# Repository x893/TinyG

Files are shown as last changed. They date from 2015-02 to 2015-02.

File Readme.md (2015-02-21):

TinyG board with BT
TinyG board with USB

Software from https://github.com/synthetos/TinyG

xboot-BT : change for Bluetooth module

xboot-loader : utility to upload (MS Visual Studio 2013) upload program with parameters -b 115200 -P COM14 -U flash:w:tinyg.hex

hardware : design files for http://akb77.com/g/cnc/tinyg-controller-for-cnc/

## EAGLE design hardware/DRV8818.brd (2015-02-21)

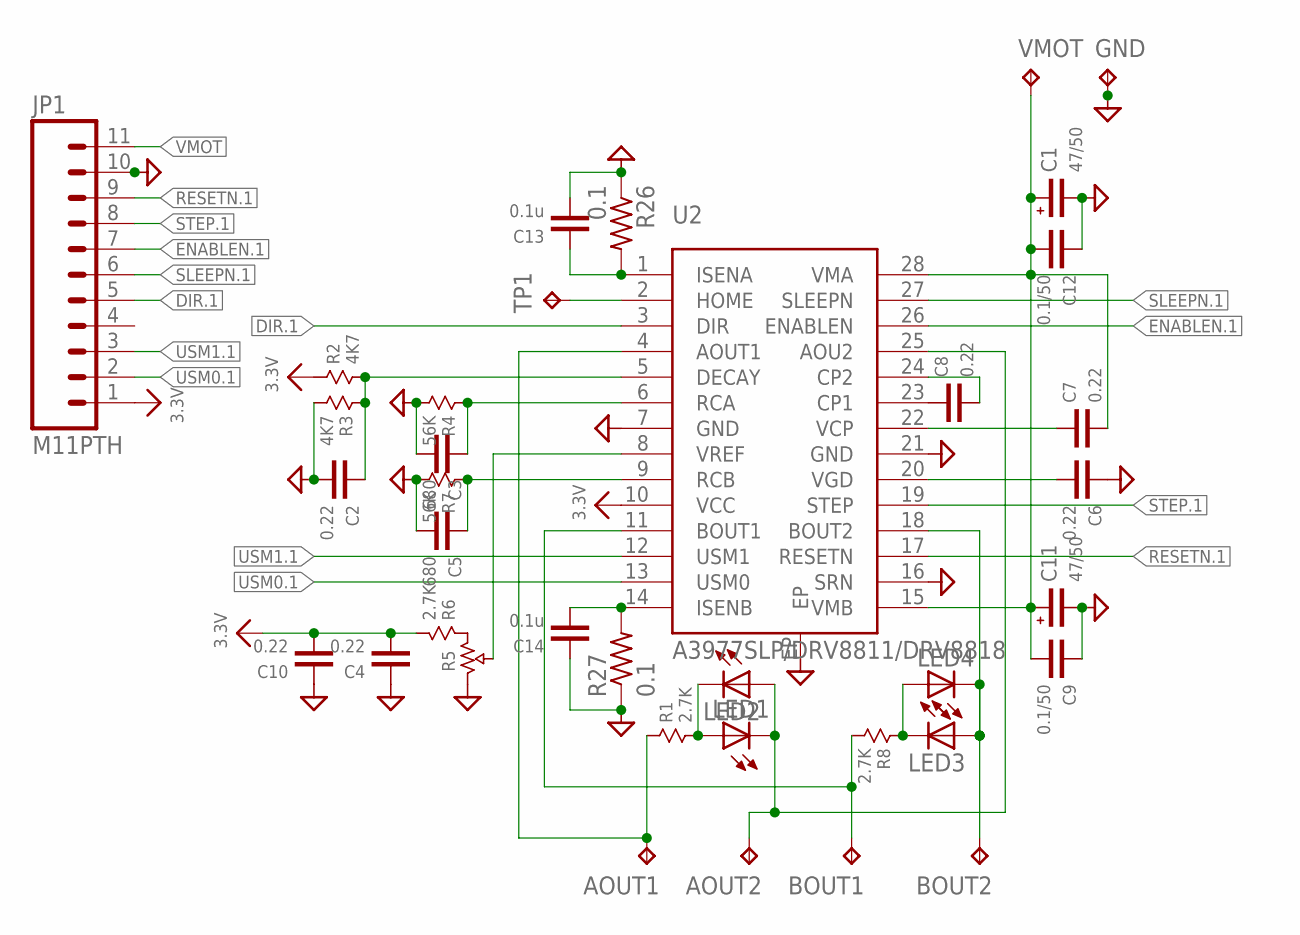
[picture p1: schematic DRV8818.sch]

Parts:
AOUT1, AOUT2: TPTP20R; TP20R
BOUT1, BOUT2: TPTP20R; TP20R
C1, C11: 47/50; CT7343
C2, C4, C6, C7, C8, C10: 0.22; 0603
C3, C5: 680; 0603
C9, C12: 0.1/50; 0603
C13, C14: 0.1u; 0603
GND: TPTP20R; TP20R
JP1: M11PTH; 1X11
LED1, LED2, LED3, LED4: LEDCHIP-LED0603; CHIP-LED0603
R1, R6, R8: 2.7K; 0603
R2, R3: 4K7; 0603
R4, R7: 56K; 0603
R5: PVZ3A
R26, R27: 0.1; R2512
TP1: TPTP08R; TP08R
U2: A3977SLP/DRV8811/DRV8818; SSOP28EP
VMOT: TPTP20R; TP20R

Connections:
3.3V: C4.1, C10.1, JP1.1, R2.1, R6.2, U2.10 (VCC)
AOUT1: AOUT1.TP, R1.1, U2.4 (AOUT1)
AOUT2: AOUT2.TP, LED1.C, LED2.A, U2.25 (AOU2)
BOUT1: BOUT1.TP, R8.2, U2.11 (BOUT1)
BOUT2: BOUT2.TP, LED3.A, LED4.C, U2.18 (BOUT2)
DIR.1: JP1.5, U2.3 (DIR)
ENABLEN.1: JP1.7, U2.26 (ENABLEN)
GND: C1.-, C2.1, C3.1, C4.2, C5.1, C6.2, C9.2, C10.2, C11.-, C12.2, C13.1, C14.2, GND.TP, JP1.10, R3.2, R4.2, R5.1, R7.2, R26.1, R27.1, U2.7 (GND), U2.16 (SRN), U2.21 (GND), U2.EP
unnamed: C14.1, R27.2, U2.14 (ISENB)
unnamed: LED3.C, LED4.A, R8.1
unnamed: LED1.A, LED2.C, R1.2
unnamed: C2.2, R2.2, R3.1, U2.5 (DECAY)
unnamed: C3.2, R4.1, U2.6 (RCA)
unnamed: R5.3, R6.1
unnamed: R5.2, U2.8 (VREF)
unnamed: C5.2, R7.1, U2.9 (RCB)
unnamed: C13.2, R26.2, U2.1 (ISENA)
unnamed: TP1.TP, U2.2 (HOME)
unnamed: C7.2, U2.22 (VCP)
unnamed: C6.1, U2.20 (VGD)
unnamed: C8.2, U2.23 (CP1)
unnamed: C8.1, U2.24 (CP2)
RESETN.1: JP1.9, U2.17 (RESETN)
SLEEPN.1: JP1.6, U2.27 (SLEEPN)
STEP.1: JP1.8, U2.19 (STEP)
USM0.1: JP1.2, U2.13 (USM0)
USM1.1: JP1.3, U2.12 (USM1)
VMOT: C1.+, C7.1, C9.1, C11.+, C12.1, JP1.11, U2.15 (VMB), U2.28 (VMA), VMOT.TP

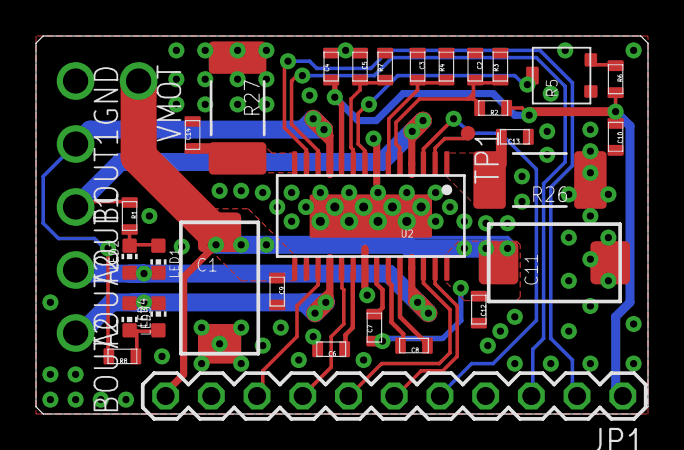
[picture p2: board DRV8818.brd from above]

Board: 2 copper layers, 34.0 x 21.0 mm, 37 parts (0 on the bottom side), 28 nets.

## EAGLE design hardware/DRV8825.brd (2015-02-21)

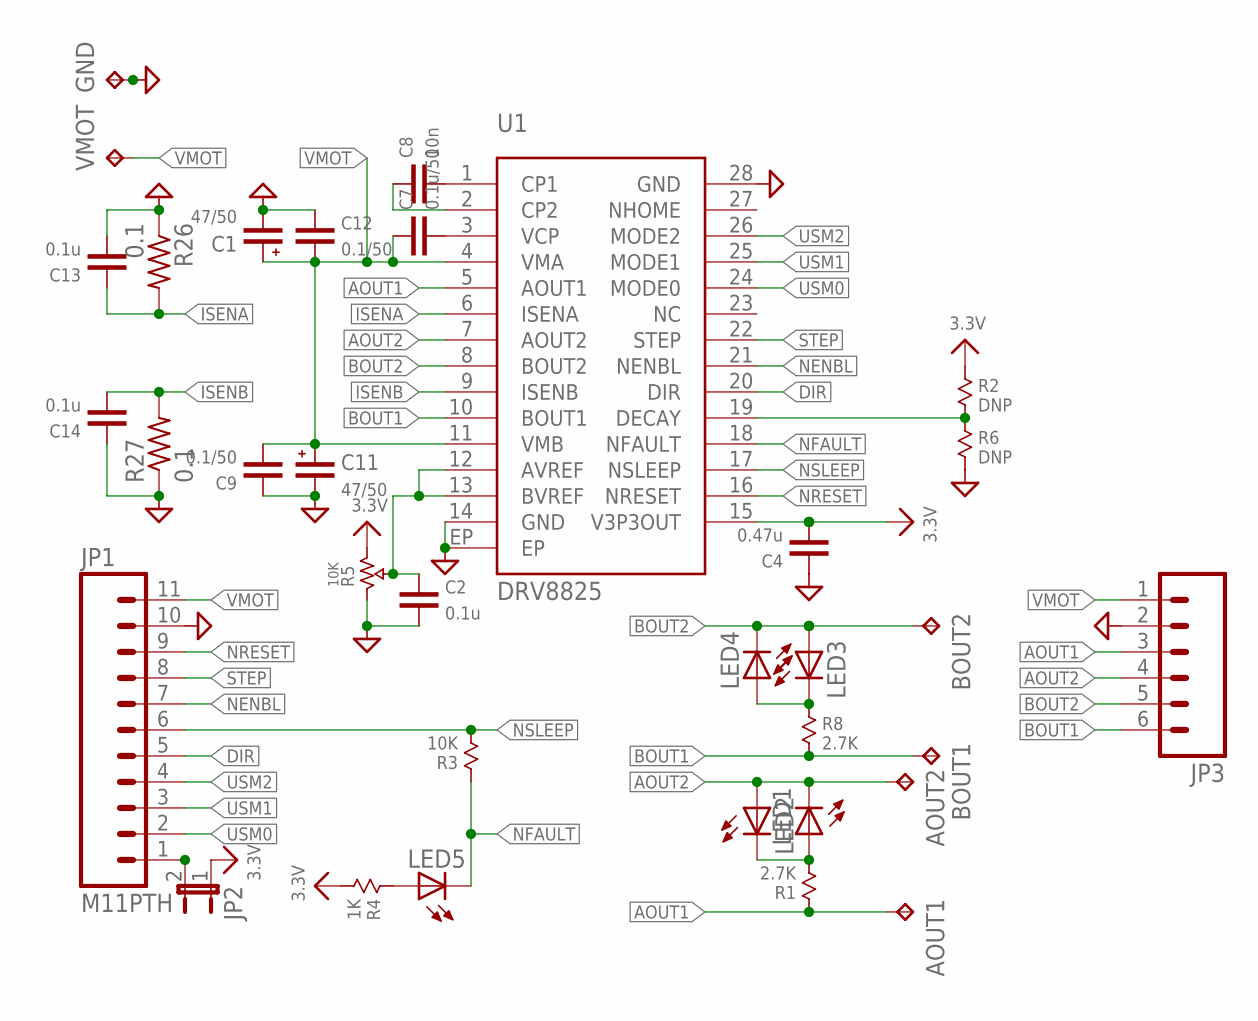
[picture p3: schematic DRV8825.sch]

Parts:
AOUT1, AOUT2: TPTP18R; TP18R
BOUT1, BOUT2: TPTP18R; TP18R
C1, C11: 47/50; CT7343
C2, C13, C14: 0.1u; 0603
C4: 0.47u; 0603
C7: 0.1u/50; 0603
C8: 10n; 0603
C9, C12: 0.1/50; 0603
GND: TPTP18R; TP18R
JP1: M11PTH; 1X11
JP2: JUMPER-2SMD-NO; SJ_2S-NO
JP3: M06SIP; 1X06
LED1, LED2, LED3, LED4, LED5: LEDCHIP-LED0603; CHIP-LED0603
R1, R8: 2.7K; 0603
R2, R6: DNP; 0603
R3: 10K; 0603
R4: 1K; 0603
R5: 10K; PVZ3A
R26, R27: 0.1; R2512
U1: DRV8825; SSOP28EP
VMOT: TPTP18R; TP18R

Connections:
3.3V: C4.1, JP2.1, R2.1, R4.2, R5.3, U1.15 (V3P3OUT)
AOUT1: AOUT1.TP, JP3.3, R1.1, U1.5 (AOUT1)
AOUT2: AOUT2.TP, JP3.4, LED1.C, LED2.A, U1.7 (AOUT2)
BOUT1: BOUT1.TP, JP3.6, R8.2, U1.10 (BOUT1)
BOUT2: BOUT2.TP, JP3.5, LED3.A, LED4.C, U1.8 (BOUT2)
DIR: JP1.5, U1.20 (DIR)
GND: C1.-, C2.1, C4.2, C9.2, C11.-, C12.2, C13.1, C14.2, GND.TP, JP1.10, JP3.2, R5.1, R6.2, R26.1, R27.1, U1.14 (GND), U1.28 (GND), U1.EP
ISENA: C13.2, R26.2, U1.6 (ISENA)
ISENB: C14.1, R27.2, U1.9 (ISENB)
unnamed: C8.1, U1.1 (CP1)
unnamed: LED3.C, LED4.A, R8.1
unnamed: LED1.A, LED2.C, R1.2
unnamed: C8.2, U1.2 (CP2)
unnamed: LED5.A, R4.1
unnamed: C7.1, U1.3 (VCP)
unnamed: C2.2, R5.2, U1.12 (AVREF), U1.13 (BVREF)
unnamed: R2.2, R6.1, U1.19 (DECAY)
unnamed: JP1.1, JP2.2
NENBL: JP1.7, U1.21 (NENBL)
NFAULT: LED5.C, R3.1, U1.18 (NFAULT)
NRESET: JP1.9, U1.16 (NRESET)
NSLEEP: JP1.6, R3.2, U1.17 (NSLEEP)
STEP: JP1.8, U1.22 (STEP)
USM0: JP1.2, U1.24 (MODE0)
USM1: JP1.3, U1.25 (MODE1)
USM2: JP1.4, U1.26 (MODE2)
VMOT: C1.+, C7.2, C9.1, C11.+, C12.1, JP1.11, JP3.1, U1.4 (VMA), U1.11 (VMB), VMOT.TP

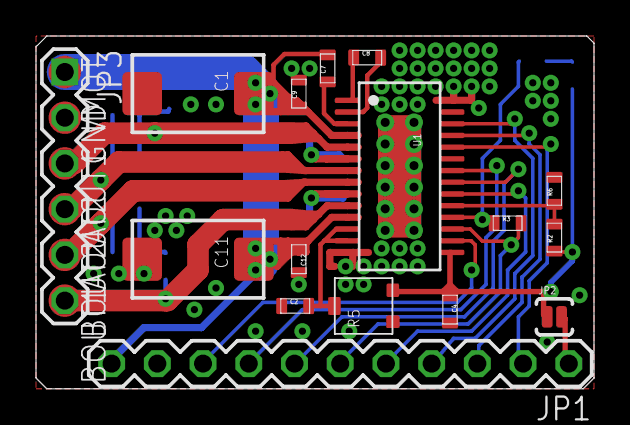
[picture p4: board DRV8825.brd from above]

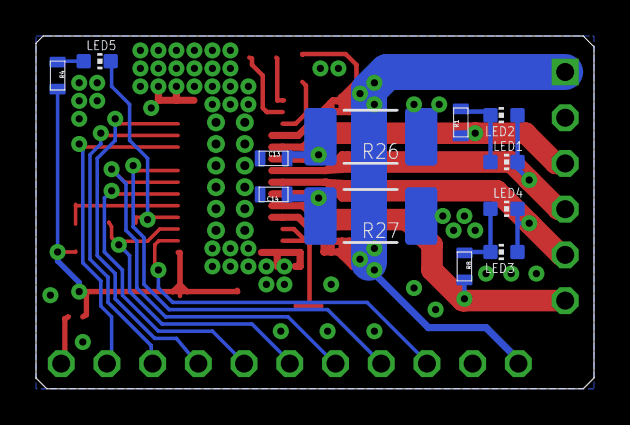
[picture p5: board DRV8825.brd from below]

Board: 2 copper layers, 31.0 x 19.6 mm, 34 parts (12 on the bottom side), 27 nets.

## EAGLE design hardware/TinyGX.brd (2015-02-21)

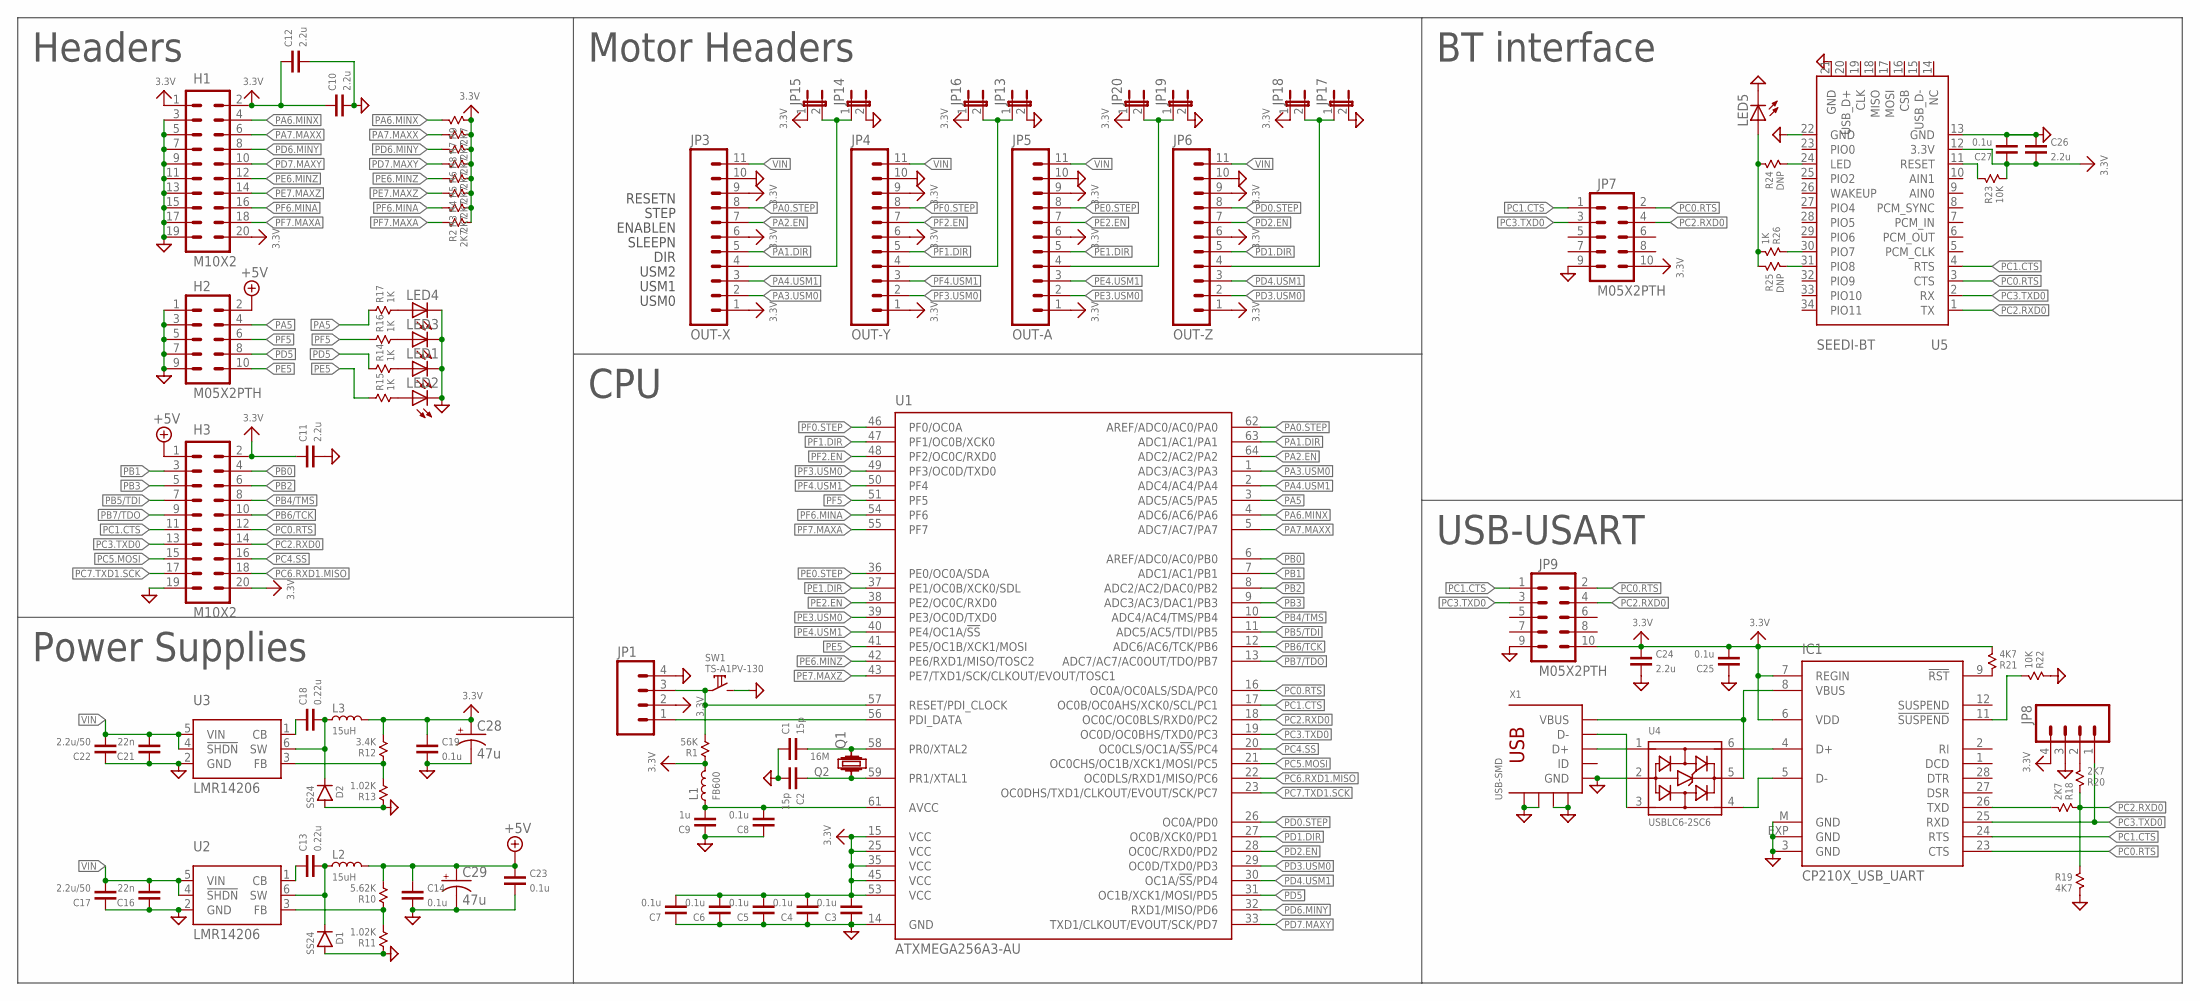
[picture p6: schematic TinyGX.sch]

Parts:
C1, C2: 15p; 0603
C3, C4, C5, C6, C7, C8, C14, C19, C23, C25, C27: 0.1u; 0603
C9: 1u; 0603
C10, C11, C12, C24, C26: 2.2u; 0603
C13, C18: 0.22u; 0603
C16, C21: 22n; 0603
C17, C22: 2.2u/50; 1206
C28, C29: 47u; CT3216
D1, D2: SS24; SMA
H1, H3: M10X2; 2X10
H2: M05X2PTH; AVR_ICSP
IC1: CP210X_USB_UART; MLP28
JP1, JP8: M04PTH; 1X04
JP3: OUT-X; 1X11
JP4: OUT-Y; 1X11
JP5: OUT-A; 1X11
JP6: OUT-Z; 1X11
JP7, JP9: M05X2PTH; AVR_ICSP
JP13, JP14, JP15, JP16, JP17, JP18, JP19, JP20: JUMPER-2SMD-NO; SJ_2S-NO
L1: FB600; 0603
L2, L3: 15uH; CDRH73
LED1, LED2, LED3, LED4, LED5: LEDCHIP-LED0603; CHIP-LED0603
Q1: CRYSTALHC49US; HC49US
Q2: 16M; KX-KT
R1: 56K; 0603
R2, R3, R4, R5, R6, R7, R8, R9, R18, R20: 2K7; 0603
R10: 5.62K; 0603
R11, R13: 1.02K; 0603
R12: 3.4K; 0603
R14, R15, R16, R17, R26: 1K; 0603
R19, R21: 4K7; 0603
R22, R23: 10K; 0603
R24, R25: DNP; 0603
SW1: TS-A1PV-130
U1: ATXMEGA256A3-AU; TQFP64-14X14
U2, U3: LMR14206; SOT23-6
U4: USBLC6-2SC6; SOT23-6
U5: SEEDI-BT
X1: USB-SMD; USB-MINIB

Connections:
3.3V: C3.1, C4.1, C5.1, C6.1, C7.1, C10.2, C11.2, C12.2, C19.2, C24.2, C25.1, C26.1, C27.2, C28.+, H1.1, H1.2, H1.20, H3.2, H3.20, IC1.6 (VDD), IC1.7 (REGIN), JP1.2, JP3.1, JP3.6, JP3.9, JP4.1, JP4.6, JP4.9, JP5.1, JP5.6, JP5.9, JP6.1, JP6.6, JP6.9, JP7.10, JP8.4, JP9.10, JP15.1, JP16.1, JP18.1, JP20.1, L1.2, L3.P$2 (2), R1.1, R2.2, R3.2, R4.2, R5.2, R6.2, R7.2, R8.2, R9.2, R12.2, R21.2, R23.2, U1.15 (VCC), U1.25 (VCC), U1.35 (VCC), U1.45 (VCC), U1.53 (VCC), U5.12 (3.3V)
+5V: C14.2, C23.2, C29.+, H2.2, H3.1, L2.P$2 (2), R10.2
GND: C1.2, C2.1, C3.2, C4.2, C5.2, C6.2, C7.2, C8.2, C9.2, C10.1, C11.1, C12.1, C14.1, C16.2, C17.2, C19.1, C21.2, C22.2, C23.1, C24.1, C25.2, C26.2, C27.1, C28.-, C29.-, D1.P$2 (A), D2.P$2 (A), H1.3, H1.5, H1.7, H1.9, H1.11, H1.13, H1.15, H1.17, H1.19, H2.1, H2.3, H2.5, H2.7, H2.9, H3.19, IC1.3 (GND), IC1.EXP (GND), IC1.M (GND), JP1.4, JP3.10, JP4.10, JP5.10, JP6.10, JP7.9, JP8.3, JP9.9, JP13.2, JP14.2, JP17.2, JP19.2, LED1.C, LED2.C, LED3.C, LED4.C, LED5.C, R11.1, R13.1, R19.2, R22.1, SW1.2, U1.14 (GND), U1.24 (GND), U1.34 (GND), U1.44 (GND), U1.52 (GND), U1.60 (GND), U2.2 (GND), U3.2 (GND), U4.2 (GND), U5.13 (GND), U5.21 (GND), U5.22 (GND), X1.GND, X1.GND@1 (GND), X1.GND@2 (GND), X1.GND@3 (GND), X1.GND@4 (GND)
unnamed: C1.1, Q1.2, Q2.2, U1.58 (PR0/XTAL2)
unnamed: C2.2, Q1.1, Q2.1, U1.59 (PR1/XTAL1)
unnamed: R10.1, R11.2, U2.3 (FB)
unnamed: LED1.A, R14.2
unnamed: C13.1, D1.P$1 (C), L2.P$1 (1), U2.6 (SW)
unnamed: R12.1, R13.2, U3.3 (FB)
unnamed: C13.2, U2.1 (CB)
unnamed: C8.1, C9.1, L1.1, U1.61 (AVCC)
unnamed: C18.1, D2.P$1 (C), L3.P$1 (1), U3.6 (SW)
unnamed: C18.2, U3.1 (CB)
unnamed: LED2.A, R15.2
unnamed: LED3.A, R16.2
unnamed: LED4.A, R17.2
unnamed: IC1.5 (D-), U4.4 (IO2)
unnamed: IC1.4 (D+), U4.6 (IO1)
unnamed: IC1.8 (VBUS), U4.5 (VBUS), X1.VBUS
unnamed: JP8.2, R20.2
unnamed: IC1.26 (TXD), R18.2
unnamed: IC1.9 (!RST), R21.1
unnamed: U4.3 (IO2), X1.D-
unnamed: U4.1 (IO1), X1.D+
unnamed: IC1.11 (!SUSPEND), R22.2
unnamed: JP3.4, JP14.1, JP15.2
unnamed: JP4.4, JP13.1, JP16.2
unnamed: JP5.4, JP19.1, JP20.2
unnamed: JP6.4, JP17.1, JP18.2
unnamed: R26.1, U5.30 (PIO7)
unnamed: R23.1, U5.11 (RESET)
unnamed: R24.2, U5.24 (LED)
unnamed: R25.2, U5.31 (PIO8)
unnamed: LED5.A, R24.1, R25.1, R26.2
PA0.STEP: JP3.8, U1.62 (AREF/ADC0/AC0/PA0)
PA1.DIR: JP3.5, U1.63 (ADC1/AC1/PA1)
PA2.EN: JP3.7, U1.64 (ADC2/AC2/PA2)
PA3.USM0: JP3.2, U1.1 (ADC3/AC3/PA3)
PA4.USM1: JP3.3, U1.2 (ADC4/AC4/PA4)
PA5: H2.4, R17.1, U1.3 (ADC5/AC5/PA5)
PA6.MINX: H1.4, R9.1, U1.4 (ADC6/AC6/PA6)
PA7.MAXX: H1.6, R7.1, U1.5 (ADC7/AC7/PA7)
PB0: H3.4, U1.6 (AREF/ADC0/AC0/PB0)
PB1: H3.3, U1.7 (ADC1/AC1/PB1)
PB2: H3.6, U1.8 (ADC2/AC2/DAC0/PB2)
PB3: H3.5, U1.9 (ADC3/AC3/DAC1/PB3)
PB4/TMS: H3.8, U1.10 (ADC4/AC4/TMS/PB4)
PB5/TDI: H3.7, U1.11 (ADC5/AC5/TDI/PB5)
PB6/TCK: H3.10, U1.12 (ADC6/AC6/TCK/PB6)
PB7/TDO: H3.9, U1.13 (ADC7/AC7/AC0OUT/TDO/PB7)
PC0.RTS: H3.12, IC1.23 (CTS), JP7.2, JP9.2, U1.16 (OC0A/OC0ALS/SDA/PC0), U5.3 (CTS)
PC1.CTS: H3.11, IC1.24 (RTS), JP7.1, JP9.1, U1.17 (OC0B/OC0AHS/XCK0/SCL/PC1), U5.4 (RTS)
PC2.RXD0: H3.14, JP7.4, JP9.4, R18.1, R19.1, R20.1, U1.18 (OC0C/OC0BLS/RXD0/PC2), U5.1 (TX)
PC3.TXD0: H3.13, IC1.25 (RXD), JP7.3, JP8.1, JP9.3, U1.19 (OC0D/OC0BHS/TXD0/PC3), U5.2 (RX)
PC4.SS: H3.16, U1.20 (OC0CLS/OC1A/!SS!/PC4)
PC5.MOSI: H3.15, U1.21 (OC0CHS/OC1B/XCK1/MOSI/PC5)
PC6.RXD1.MISO: H3.18, U1.22 (OC0DLS/RXD1/MISO/PC6)
PC7.TXD1.SCK: H3.17, U1.23 (OC0DHS/TXD1/CLKOUT/EVOUT/SCK/PC7)
PD0.STEP: JP6.8, U1.26 (OC0A/PD0)
PD1.DIR: JP6.5, U1.27 (OC0B/XCK0/PD1)
PD2.EN: JP6.7, U1.28 (OC0C/RXD0/PD2)
PD3.USM0: JP6.2, U1.29 (OC0D/TXD0/PD3)
PD4.USM1: JP6.3, U1.30 (OC1A/!SS!/PD4)
PD5: H2.8, R14.1, U1.31 (OC1B/XCK1/MOSI/PD5)
PD6.MINY: H1.8, R8.1, U1.32 (RXD1/MISO/PD6)
PD7.MAXY: H1.10, R6.1, U1.33 (TXD1/CLKOUT/EVOUT/SCK/PD7)
PDI: JP1.1, U1.56 (PDI_DATA)
PE0.STEP: JP5.8, U1.36 (PE0/OC0A/SDA)
PE1.DIR: JP5.5, U1.37 (PE1/OC0B/XCK0/SDL)
PE2.EN: JP5.7, U1.38 (PE2/OC0C/RXD0)
PE3.USM0: JP5.2, U1.39 (PE3/OC0D/TXD0)
PE4.USM1: JP5.3, U1.40 (PE4/OC1A/!SS)
PE5: H2.10, R15.1, U1.41 (PE5/OC1B/XCK1/MOSI)
PE6.MINZ: H1.12, R5.1, U1.42 (PE6/RXD1/MISO/TOSC2)
PE7.MAXZ: H1.14, R4.1, U1.43 (PE7/TXD1/SCK/CLKOUT/EVOUT/TOSC1)
PF0.STEP: JP4.8, U1.46 (PF0/OC0A)
PF1.DIR: JP4.5, U1.47 (PF1/OC0B/XCK0)
PF2.EN: JP4.7, U1.48 (PF2/OC0C/RXD0)
PF3.USM0: JP4.2, U1.49 (PF3/OC0D/TXD0)
PF4.USM1: JP4.3, U1.50 (PF4)
PF5: H2.6, R16.1, U1.51 (PF5)
PF6.MINA: H1.16, R3.1, U1.54 (PF6)
PF7.MAXA: H1.18, R2.1, U1.55 (PF7)
RST/PDC: JP1.3, R1.2, SW1.1, U1.57 (RESET/PDI_CLOCK)
VIN: C16.1, C17.1, C21.1, C22.1, JP3.11, JP4.11, JP5.11, JP6.11, U2.4 (!SHDN), U2.5 (VIN), U3.4 (!SHDN), U3.5 (VIN)

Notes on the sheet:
USM0
USM1
DIR
SLEEPN
ENABLEN
STEP
RESETN
USM2
BT interface
USB-USART
Motor Headers
CPU
Power Supplies
Headers

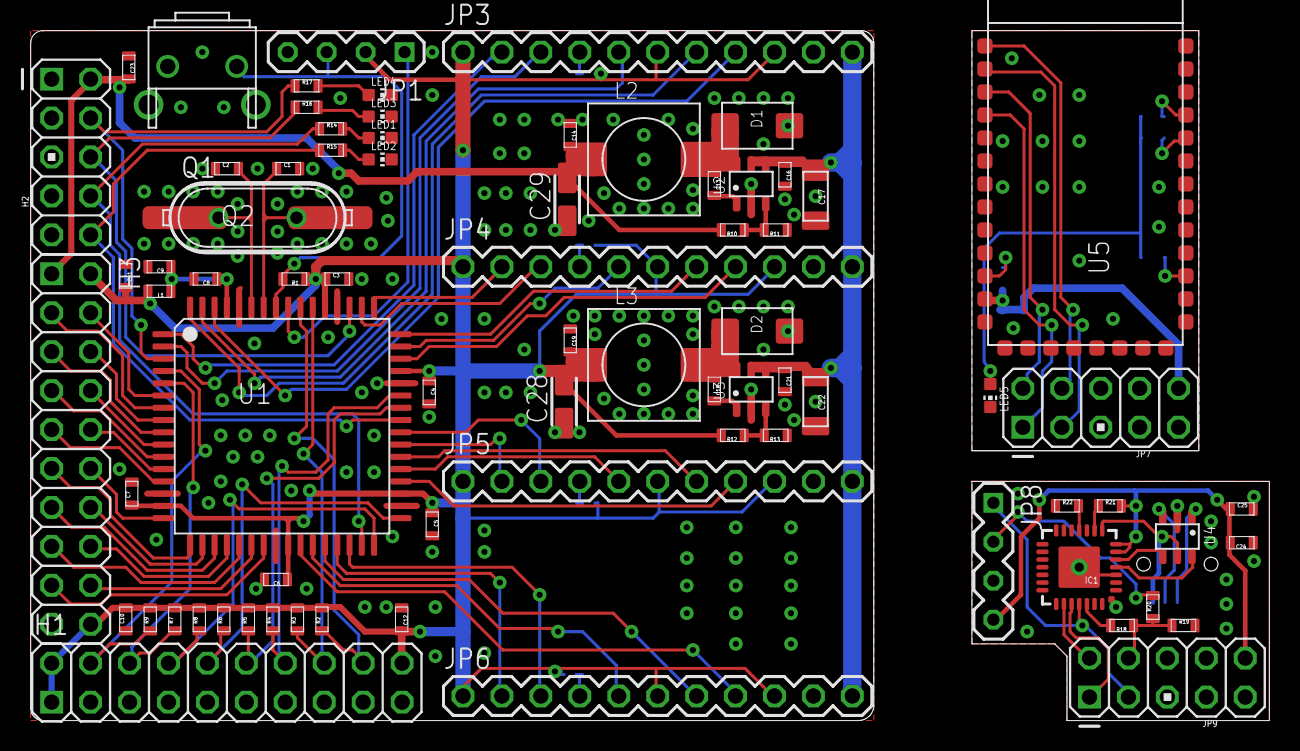
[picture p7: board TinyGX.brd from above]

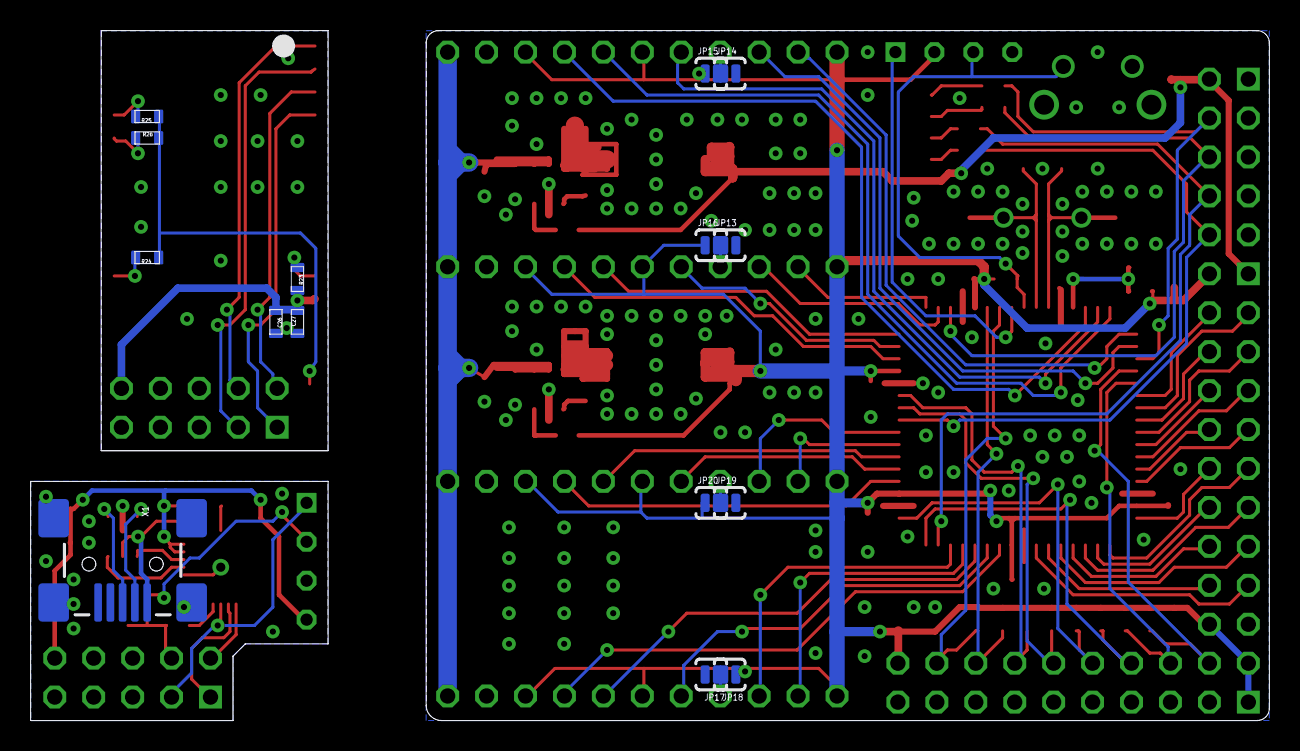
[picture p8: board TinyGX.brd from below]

Board: 2 copper layers, 80.8 x 45.0 mm, 92 parts (15 on the bottom side), 85 nets.

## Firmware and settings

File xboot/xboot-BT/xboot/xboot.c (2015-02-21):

#include "xboot.h"

unsigned char Buffer[SPM_PAGESIZE];
ADDR_T address;
uint16_t data;
uint8_t in_bootloader;
uint8_t val;
uint32_t led_delay;

typedef struct FirmwareInfo_s {
	uint32_t	Size;
	uint16_t	CRC16;
	} FirmwareInfo_t;

#define FWINFO_START	(APP_SECTION_START + APP_SECTION_SIZE - APP_SECTION_PAGE_SIZE)
uint8_t CheckAppImage(void);
void WriteAppChecksum(uint32_t size);

// Main code
int main(void)
{
	WDT_Disable();

	#ifdef USE_32MHZ_RC
		#if (F_CPU != 32000000L)
			#error F_CPU must match oscillator setting!
		#endif // F_CPU

		OSC.CTRL |= OSC_RC32MEN_bm;						// turn on 32 MHz oscillator
		while (!(OSC.STATUS & OSC_RC32MRDY_bm)) { };	// wait for it to start
		CCP = CCP_IOREG_gc;
		CLK.CTRL = CLK_SCLKSEL_RC32M_gc;

		#ifdef USE_DFLL
			DFLLRC32M.CTRL = DFLL_ENABLE_bm;
		#endif // USE_DFLL
	#else // USE_32MHZ_RC
		#if (F_CPU != 2000000L)
			#error F_CPU must match oscillator setting!
		#endif // F_CPU
		#ifdef USE_DFLL
			DFLLRC2M.CTRL = DFLL_ENABLE_bm;
		#endif // USE_DFLL
	#endif // USE_32MHZ_RC

	LED_INIT();
	// Bluetooth initialization 
	UART_INIT(USART_BAUD_9600);
	UART_Send_B("AT+BAUD8");		// Set speed 115200
	_delay_ms(1000);
	UART_INIT(USART_BAUD_115200);	// Change USART to 115200
	UART_Send_B("AT+NAMETinyG");	// Set BT device name
	_delay_ms(1000);
	UART_Send_B("AT+PIN1963");		// Set BT password
	_delay_ms(1000);

	// Correct CRC, enable auto jump to application
	in_bootloader = CheckAppImage();
	//	in_bootloader == 1	CRC not correct, never jump to application
	//	in_bootloader == 2	CRC correct, after small delay go to application
	data = 0;
	address = 0;
	led_delay = 0;
	while (in_bootloader)	// Main bootloader
	{
		val = get_char_nowait();
		if (val == 0)
		{
			led_delay++;
			if (led_delay == LED_ON_DELAY)
			{
				LED_ON();
			}
			else if (led_delay == LED_OFF_DELAY)
			{
				LED_OFF();
				led_delay = 0;
				if (in_bootloader == XB_BOOT_DELAY)
				{	// Jump to application
					in_bootloader = 0;
					break;
				}					
				else if (in_bootloader > 1)
				{	// Correct CRC, increment boot delay
					in_bootloader++;
				}					
			}
			continue;
		}
		led_delay = 0;
		LED_ON();

		in_bootloader = 1;	// Disable auto start application
		if (val == CMD_CHECK_AUTOINCREMENT)
		{
			UART_Send(REPLY_YES);
		}
		else if (val == CMD_SET_ADDRESS)
		{	// Set address
			address = get_2bytes();	// Read address high then low
			UART_Send(REPLY_ACK);
		}
		else if (val == CMD_SET_EXT_ADDRESS)
		{	// Extended address
			// Read address high then low
			address = get_3bytes();
			UART_Send(REPLY_ACK);
		}
		else if (val == CMD_CHIP_ERASE)
		{	// Chip erase
			Flash_EraseApplicationSection();	// Erase the application section
			SP_WaitForSPM();					// Wait for completion
			EEPROM_erase_all();					// Erase EEPROM
			UART_Send(REPLY_ACK);
		}
		else if (val == CMD_CHECK_BLOCK_SUPPORT )
		{	// Check block load support
			UART_Send(REPLY_YES);
			UART_Send((SPM_PAGESIZE >> 8) & 0xFF);	// Send block size (page size)
			UART_Send(SPM_PAGESIZE & 0xFF);
		}
		else if (val == CMD_BLOCK_LOAD)
		{	// Block load
			int bsize = get_2bytes();	// Block size
			val = get_char();			// Memory type
			UART_Send(BlockLoad(bsize, val, &address));
		}
		else if (val == CMD_BLOCK_READ)
		{	// Block read
			int bsize = get_2bytes();	// Block size
			val = get_char();			// Memory type
			BlockRead(bsize, val, &address);
		}
		else if (val == CMD_READ_BYTE)
		{	// Read program memory byte
			unsigned int w = Flash_ReadWord((address << 1));
			UART_Send(w >> 8);
			UART_Send(w);
			address++;
		}
		else if (val == CMD_WRITE_LOW_BYTE)
		{	// Write program memory low byte
			data = get_char();	// get low byte
			UART_Send(REPLY_ACK);
		}
		else if (val == CMD_WRITE_HIGH_BYTE)
		{	// Write program memory high byte
			data |= (get_char() << 8);		// get high byte; combine
			Flash_LoadFlashWord((address << 1), data);
			address++;
			UART_Send(REPLY_ACK);
		}
		else if (val == CMD_WRITE_PAGE)
		{	// Write page
			if (address >= (APP_SECTION_SIZE >> 1))
			{	// don't allow bootloader overwrite
				UART_Send(REPLY_ERROR);
			}
			else
			{
				Flash_WriteApplicationPage( address << 1);
				UART_Send(REPLY_ACK);
			}
		}
		else if (val == CMD_WRITE_EEPROM_BYTE)
		{	// Write EEPROM memory
			EEPROM_write_byte(address, get_char());
			address++;
		}
		else if (val == CMD_READ_EEPROM_BYTE)
		{	// Read EEPROM memory
			char c = EEPROM_read_byte(address);
			UART_Send(c);
			address++;
		}
		else if (val == CMD_WRITE_LOCK_BITS)
		{	// Write lockbits
			SP_WriteLockBits( get_char() );
			UART_Send(REPLY_ACK);
		}
		else if (val == CMD_READ_LOCK_BITS)
		{	// Read lockbits
			UART_Send(SP_ReadLockBits());
		}
		else if (val == CMD_READ_LOW_FUSE_BITS)
		{	// Read low fuse bits
			UART_Send(SP_ReadFuseByte(0));
		}
		else if (val == CMD_READ_HIGH_FUSE_BITS)
		{	// Read high fuse bits
			UART_Send(SP_ReadFuseByte(1));
		}
		else if (val == CMD_READ_EXT_FUSE_BITS)
		{	// Read extended fuse bits
			UART_Send(SP_ReadFuseByte(2));
		}
		// Enter and leave programming mode
		else if ((val == CMD_ENTER_PROG_MODE) || (val == CMD_LEAVE_PROG_MODE))
		{	// just acknowledge
			UART_Send(REPLY_ACK);
		}
		else if (val == CMD_EXIT_BOOTLOADER)
		{	// Exit bootloader
			if (CheckAppImage() == 2)
			{
				in_bootloader = 0;
				UART_Send(REPLY_ACK);
			}
			else
				UART_Send(REPLY_ERROR);
		}
		else if (val == CMD_PROGRAMMER_TYPE)
		{	// Get programmer type
			UART_Send('S');
		}
		else if (val == CMD_DEVICE_CODE)
		{	// Return supported device codes
			// send only this device
			UART_Send(123); // TODO
			UART_Send(0);
		}
		else if ((val == CMD_SET_LED) || (val == CMD_CLEAR_LED) || (val == CMD_SET_TYPE))
		{	// Set LED, clear LED, and set device type
			get_char();	// discard parameter
			UART_Send(REPLY_ACK);
		}
		else if (val == CMD_PROGRAM_ID)
		{	// Return program identifier
			UART_Send('X');
			UART_Send('B');
			UART_Send('o');
			UART_Send('o');
			UART_Send('t');
			UART_Send('+');
			UART_Send('+');
		}
		else if (val == CMD_VERSION)
		{	// Read software version
			UART_Send('0' + XBOOT_VERSION_MAJOR);
			UART_Send('0' + XBOOT_VERSION_MINOR);
		}
		else if (val == CMD_READ_SIGNATURE)
		{	// Read signature bytes
			UART_Send(SIGNATURE_2);
			UART_Send(SIGNATURE_1);
			UART_Send(SIGNATURE_0);
		}
		//	hA
		else if (val == CMD_CRC)
		{
			uint32_t start = 0;
			uint32_t length = 0;
			uint16_t crc;

			val = get_char();

			switch (val)
			{
				case SECTION_FLASH:
					length = PROGMEM_SIZE;
					break;
				case SECTION_APPLICATION:
					length = APP_SECTION_SIZE;
					break;
				case SECTION_BOOT:
					start = BOOT_SECTION_START;
					length = BOOT_SECTION_SIZE;
					break;
				case SECTION_CUSTOM:
					start = address;	// Use Set extended address
					length = get_3bytes();
					break;
			}
			if (length != 0)
			{
				crc = crc16_block(start, length);
				UART_Send(REPLY_ACK);
				UART_Send((crc >> 8) & 0xFF);
				UART_Send(crc & 0xFF);
			}
			else
			{
				UART_Send(REPLY_ERROR);
				UART_Send(0);
				UART_Send(0);
			}
		}
		else if (val == CMD_CRC_WRITE)
		{
			WriteAppChecksum(get_3bytes());
			UART_Send(REPLY_ACK);
		}
		else if (val != CMD_SYNC)
		{
			UART_Send(REPLY_ACK);
		}

		// Wait for any lingering SPM instructions to finish
		Flash_WaitForSPM();
		LED_OFF();
	}

	// Bootloader exit section
	// Code here runs after the bootloader has exited,
	// but before the application code has started
	// --------------------------------------------------

	UART_DEINIT();
	LED_ON();

	asm("jmp 0");	// Jump into main code

#ifdef __builtin_unreachable
	// Size optimization as the asm jmp will not return
	// However, it seems it is not available on older versions of gcc
	__builtin_unreachable();
#endif
}

unsigned char __attribute__ ((noinline)) get_char(void)
{
	while (!uart_char_received());
	return uart_cur_char();
}

unsigned char __attribute__ ((noinline)) get_char_nowait(void)
{
	if (uart_char_received())
		return uart_cur_char();
	return 0;
}

uint32_t __attribute__ ((noinline)) get_3bytes()
{
	uint32_t val = ((uint32_t)get_char() << 16);
	return  val | (uint32_t)get_2bytes();
}

uint16_t __attribute__ ((noinline)) get_2bytes()
{
	uint16_t val = ((uint16_t)get_char() << 8);
	return  val | (uint16_t)get_char();
}

void clear_buffer(void)
{
	unsigned char *ptr = Buffer;
	for (long i = 0; i < SPM_PAGESIZE; i++)
		*(ptr++) = 0xFF;
}

unsigned char BlockLoad(unsigned int size, unsigned char mem, ADDR_T *address)
{
	ADDR_T tempaddress;

	// fill up Buffer
	for (int i = 0; i < SPM_PAGESIZE; i++)
	{
		char c = 0xFF;
		if (i < size)
			c = get_char();
		Buffer[i] = c;
	}

	// EEPROM memory type.
	if(mem == MEM_EEPROM)
	{
		EEPROM_write_block(*address, Buffer, size);
		(*address) += size;
		return REPLY_ACK; // Report programming OK
	}

	else if (mem == MEM_FLASH || mem == MEM_USERSIG)
	{	// NOTE: For flash programming, 'address' is given in words.
		tempaddress = (*address) << 1;  // Store address in page.
		(*address) += size >> 1;
		if (mem == MEM_FLASH)
		{
			Flash_ProgramPage(tempaddress, Buffer, 1);
		}
		else if (mem == MEM_USERSIG)
		{
			Flash_LoadFlashPage(Buffer);
			Flash_EraseUserSignatureRow();
			Flash_WaitForSPM();
			Flash_WriteUserSignatureRow();
			Flash_WaitForSPM();
		}
		return REPLY_ACK;
	}
	else
		return REPLY_ERROR;
}

void BlockRead(unsigned int size, unsigned char mem, ADDR_T *address)
{
	int offset = 0;
	int size2 = size;
        
	// EEPROM memory type.
        
	if (mem == MEM_EEPROM) // Read EEPROM
	{
		EEPROM_read_block(*address, Buffer, size);
		(*address) += size;
	}
	// Flash memory type.
	else if (mem == MEM_FLASH || mem == MEM_USERSIG || mem == MEM_PRODSIG)
	{
		(*address) <<= 1; // Convert address to bytes temporarily.
		do
		{
			if (mem == MEM_FLASH)
				Buffer[offset++] = Flash_ReadByte(*address);
			else if (mem == MEM_USERSIG)
				Buffer[offset++] = SP_ReadUserSignatureByte(*address);
			else if (mem == MEM_PRODSIG)
				Buffer[offset++] = SP_ReadCalibrationByte(*address);
			Flash_WaitForSPM();
			(*address)++;    // Select next word in memory.
			size--;          // Subtract two bytes from number of bytes to read
		} while (size);         // Repeat until all block has been read
		(*address) >>= 1;       // Convert address back to Flash words again.
	}
	else
		// bad memory type
		return;

	// send bytes
	for (int i = 0; i < size2; i++)
		UART_Send(Buffer[i]);
}

uint16_t crc16_block(uint32_t start, uint32_t length)
{
	uint16_t crc = 0;
	int bc = SPM_PAGESIZE;

	for ( ; length > 0; length--)
	{
		if (bc == SPM_PAGESIZE)
		{
			Flash_ReadFlashPage(Buffer, start);
			start += SPM_PAGESIZE;
			bc = 0;
		}
		crc = _crc16_update(crc, Buffer[bc]);
		bc++;
	}
	return crc;
}

uint8_t CheckAppImage(void)
{
	uint32_t app_size;
	uint16_t app_crc;
	FirmwareInfo_t *fw_info = (FirmwareInfo_t *)&Buffer[0];

	Flash_ReadFlashPage(Buffer, FWINFO_START);
	app_size = fw_info->Size;
	app_crc = fw_info->CRC16;
	if (app_size != 0xFFFFFFFF)
	{
		data = crc16_block(APP_SECTION_START, fw_info->Size);
		if (app_crc == data)
			return 2;
	}
	return 1;
}

void WriteAppChecksum(uint32_t size)
{
	FirmwareInfo_t *fw_info = (FirmwareInfo_t *)&Buffer[0];

	data = crc16_block(APP_SECTION_START, size);
	Flash_ReadFlashPage(Buffer, FWINFO_START);
	if (size != fw_info->Size || data != fw_info->Size)
	{
		for (int i = 0; i < APP_SECTION_PAGE_SIZE; i++)
			Buffer[i] = 0xFF;

		fw_info->Size = size;
		fw_info->CRC16 = data;
		Flash_ProgramPage(FWINFO_START, Buffer, 1);
		Flash_WaitForSPM();
	}
}

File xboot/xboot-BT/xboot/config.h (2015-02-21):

// XBoot config header file
// MCU: atxmega256a3
// F_CPU: 32000000

#define LED_PIN			5
#define LED_PORT		PORTA
#define LED_ON()
//	LED_PORT.OUTSET = (1 << LED_PIN)
#define LED_OFF()
//	LED_PORT.OUTCLR = (1 << LED_PIN)
#define LED_TOGGLE()
//	LED_PORT.OUTTGL = (1 << LED_PIN)
#define LED_INIT()
/*	do {							\
		LED_ON();					\
		LED_PORT.DIRSET = (1 << LED_PIN);	\
	} while(0)
*/
#define LED_ON_DELAY		500000UL
#define LED_OFF_DELAY		540000UL
#define XB_BOOT_DELAY		7

#define UART_BAUD_RATE		115200

#if (UART_NUMBER == 0)
	#define UART_RX_PIN		2
	#define UART_TX_PIN		3
#else
	#define UART_RX_PIN		6
	#define UART_TX_PIN		7
#endif

#define UART_PORT			PORTC
#define UART_DEVICE_PORT	C0
#define UART_DEVICE			USARTC0
#define UART_RX_PIN_CTRL	PORTC.PIN2CTRL
#define UART_TX_PIN_CTRL	PORTC.PIN3CTRL

#define UART_INIT(b)		USARTC0_Init(b)
#define UART_DEINIT()		USARTC0_DeInit()
#define UART_Send(c)		USARTC0_Send(c)
#define UART_Send_B(s)		USARTC0_Send_B(PSTR(s))
#define UART_Send_Hex4(d)	USART_Send_Hex4(&UART_DEVICE, d)
#define UART_Send_Hex2(d)	USART_Send_Hex2(&UART_DEVICE, d)

#define WATCHDOG_TIMEOUT	WDT_PER_1KCLK_gc

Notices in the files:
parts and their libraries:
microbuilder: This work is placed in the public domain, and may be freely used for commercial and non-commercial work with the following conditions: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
